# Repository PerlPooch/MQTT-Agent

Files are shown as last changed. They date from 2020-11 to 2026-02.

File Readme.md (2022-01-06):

# Spencer MQTT Agent

## MQTT Topic

	spencer/<ID>/<device>
		<ID> := unique MAC address of device
		<device> := temperature|status|relay
		
## Payload (JSON object):

	{
		"command": "fetch"|"set-rate"|"set"
		"rate": int: seconds between updates
		"device-num": int: 0-based index of device 
		"state": "on"|"off"|"pulse"
	}

	command == "fetch"
		Causes agent to publish information for <device>

	command == "set-rate"
		Sets update rate for <device> to rate in rate. <device> can be temperature or status

	command == "set"
		Sets <device> at index device-num to state. <device> can be relay. <state> can be on, off, or pulse.
		
## Examples:

	spencer/FC:F5:C4:AB:56:24/temperature {"command":"set-rate", "rate":"120"}
		Set the update rate for temperature reports to be 120 seconds

	spencer/FC:F5:C4:AB:56:24/status {"command":"set-rate", "rate":"300"}
		Set the update rate for status reports to be 300 seconds

	spencer/FC:F5:C4:AB:56:24/relay {"command":"set", "device-num":"1", "state":"on"}
		Turn on relay 0

	spencer/FC:F5:C4:AB:56:24/relay {"command":"set", "device-num":"1", "state":"off"}
		Turn off relay 1

	spencer/FC:F5:C4:AB:56:24/relay {"command":"set", "device-num":"0", "state":"pulse"}
		Pulse relay 0

	spencer/FC:F5:C4:AB:56:24/temperature {"command":"fetch"}
		Request publish of temperature

	spencer/FC:F5:C4:AB:56:24/status {"command":"fetch"}
		Request publish of input status

	spencer/FC:F5:C4:AB:56:24/relay {"command":"fetch"}
		Request publish of relay status

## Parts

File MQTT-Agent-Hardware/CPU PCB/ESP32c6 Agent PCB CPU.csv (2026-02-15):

Id | Designator | Footprint | Quantity | Designation | Supplier and ref
1 | J1 | Connector SIP-14-Soldertail-R | 1 | Screw_Terminal_01x14
2 | R2,R1,R3,R4 | R_1206_3216Metric_Pad1.30x1.75mm_HandSolder | 4 | 10K
3 | SW1,SW2,SW3 | SW_PUSH_6mm_H4.3mm | 3 | SW_Push
4 | U2 | DFPlayer | 1 | DFPlayer_Module
5 | C3,C4 | C_1206_3216Metric_Pad1.33x1.80mm_HandSolder | 2 | X7R 100nF 25V
6 | C1,C2 | C_0805_2012Metric_Pad1.18x1.45mm_HandSolder | 2 | X7R 1.0uF 25V
7 | U5 | XIAO-ESP32C6-DIP | 1 | XIAO-ESP32-C6
8 | R12 | R_1206_3216Metric_Pad1.30x1.75mm_HandSolder | 1 | 4.7K
9 | U1 | SSD1306-128x32 | 1 | ~
10 | J2 | Molex_KK-254_AE-6410-02A_1x02_P2.54mm_Vertical | 1 | Power
11 | R5 | R_1206_3216Metric_Pad1.30x1.75mm_HandSolder | 1 | 1K
12 | U6 | SSOP-14_5.3x6.2mm_P0.65mm | 1 | 74AHCT125

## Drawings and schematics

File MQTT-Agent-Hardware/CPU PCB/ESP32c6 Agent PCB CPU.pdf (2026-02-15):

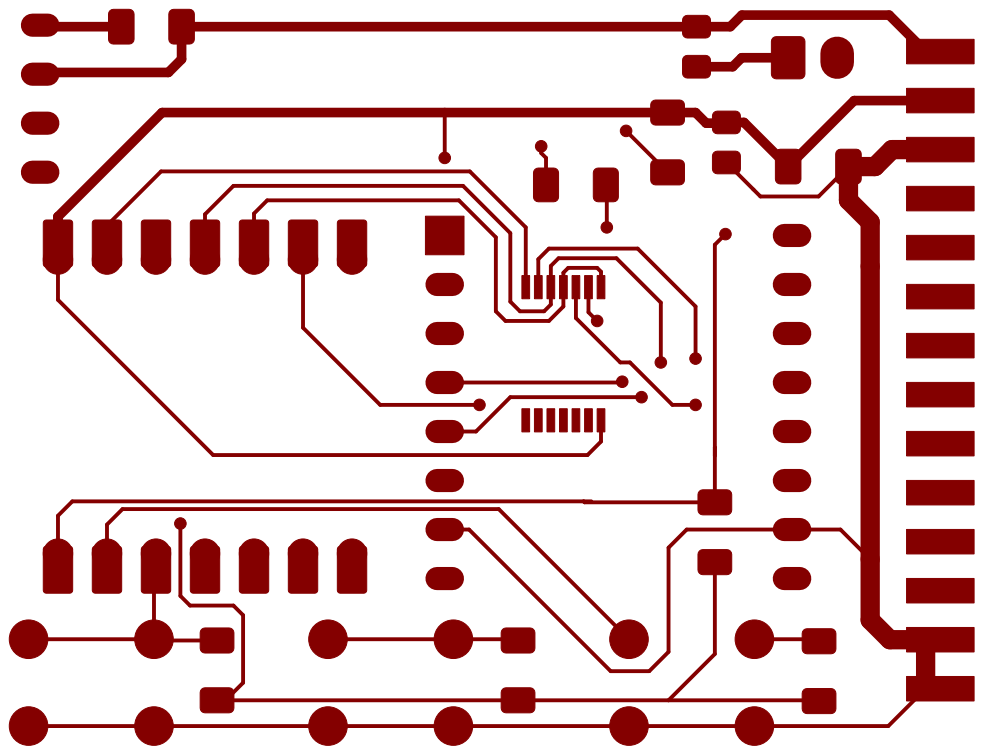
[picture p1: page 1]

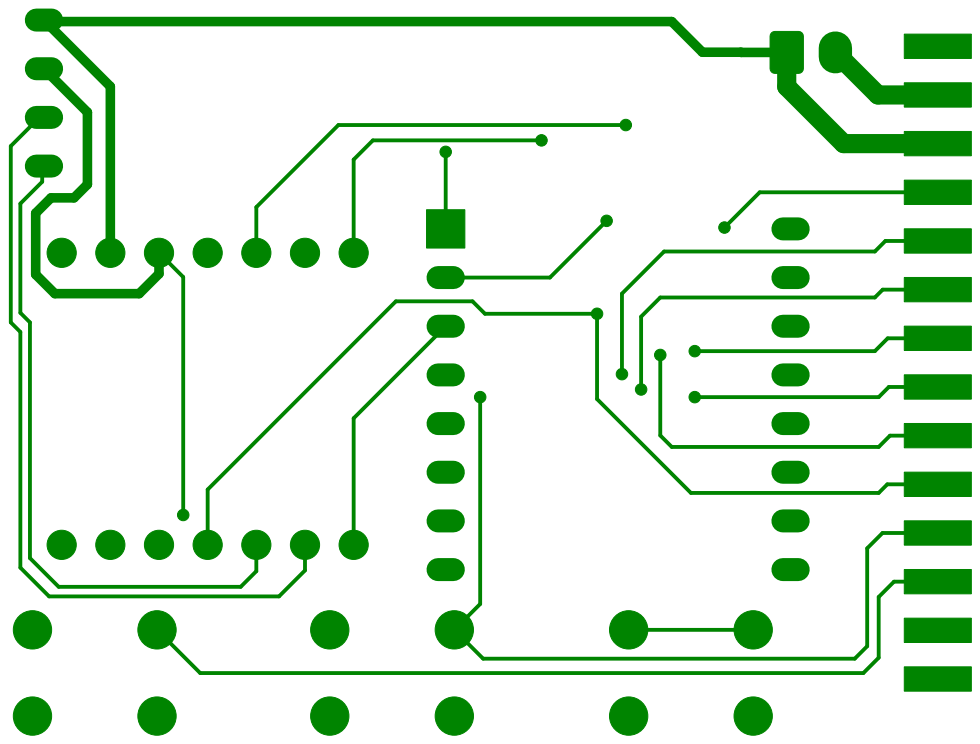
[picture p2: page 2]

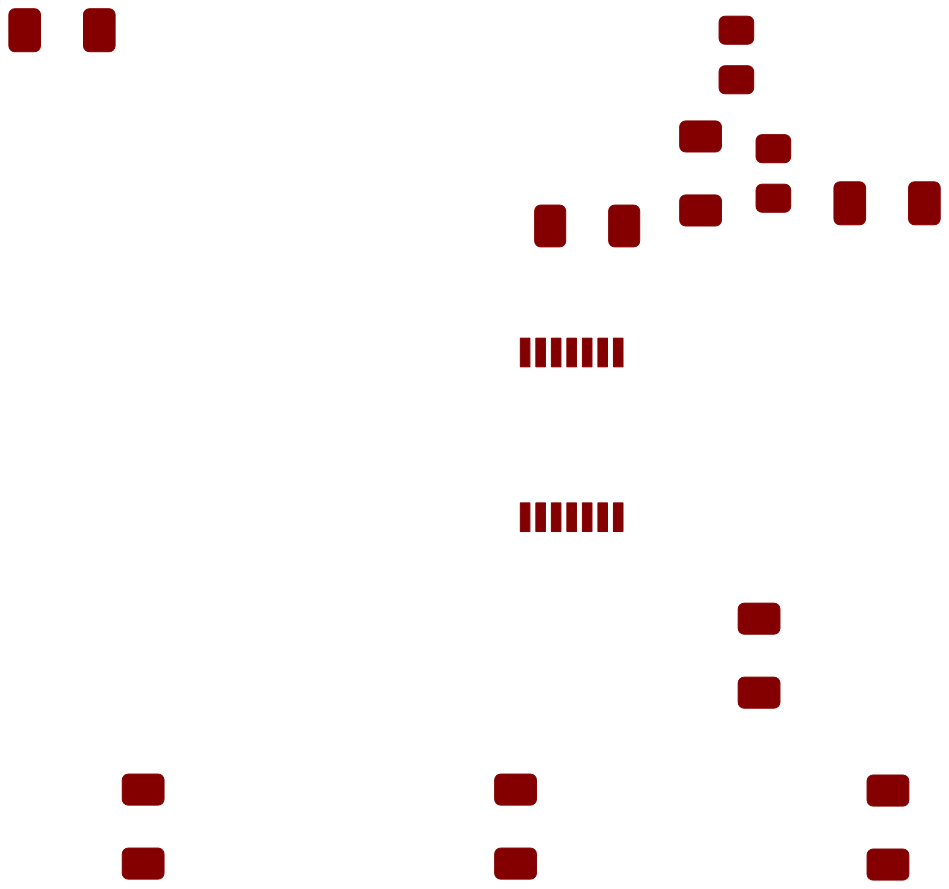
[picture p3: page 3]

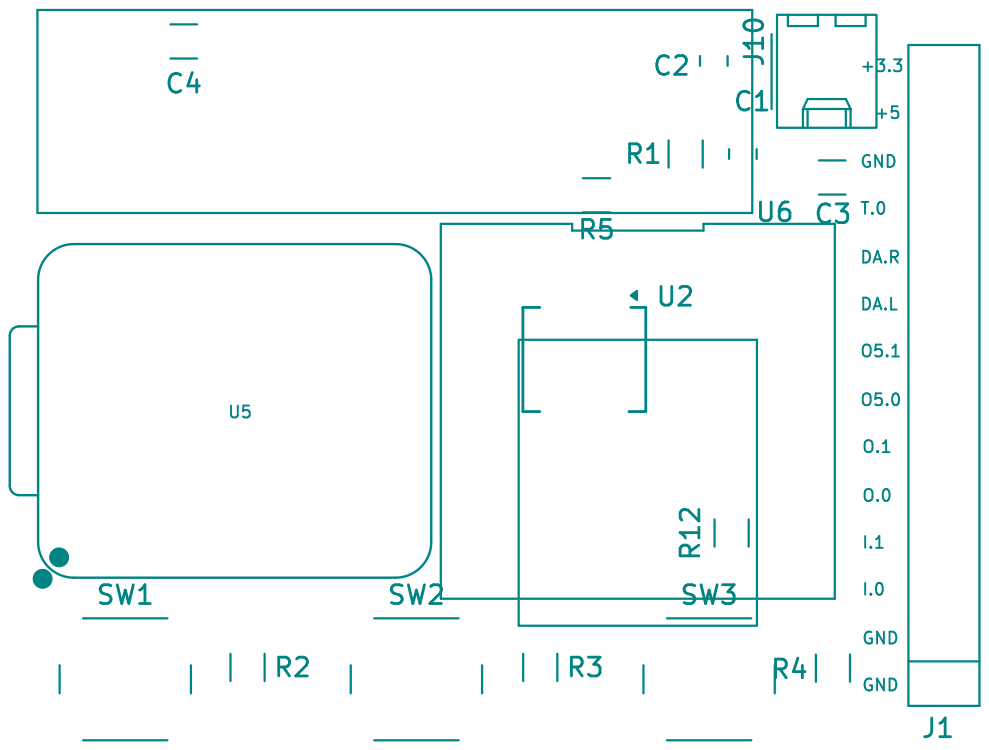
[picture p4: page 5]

+3.3 GND O5.0 DA.R GND O5.1 +5 DA.L T.0

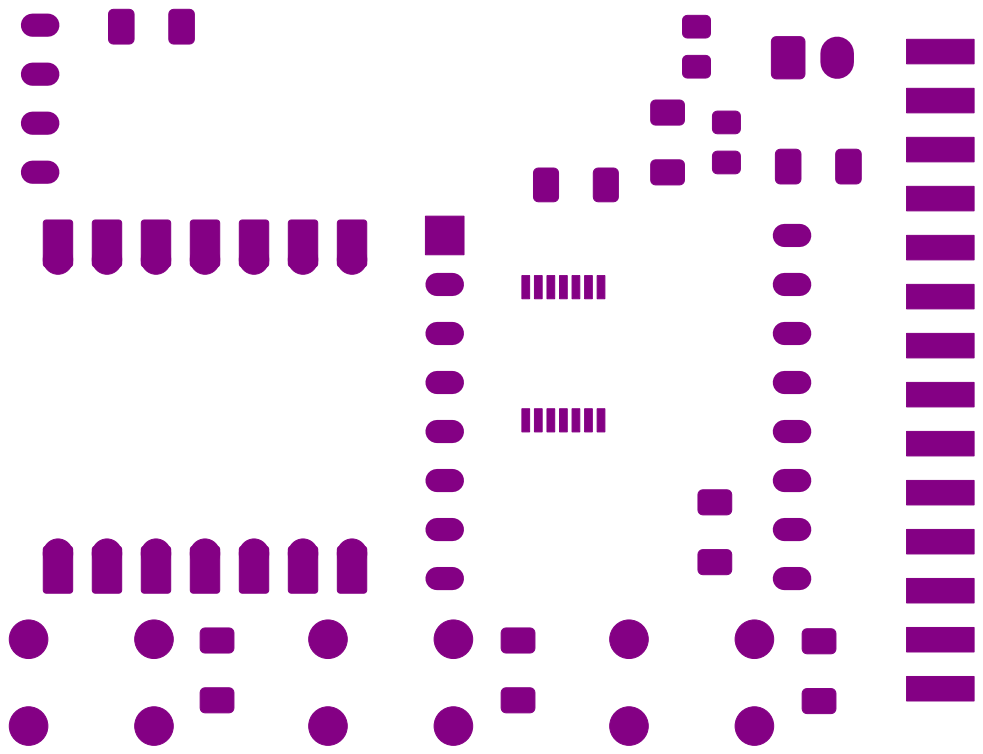
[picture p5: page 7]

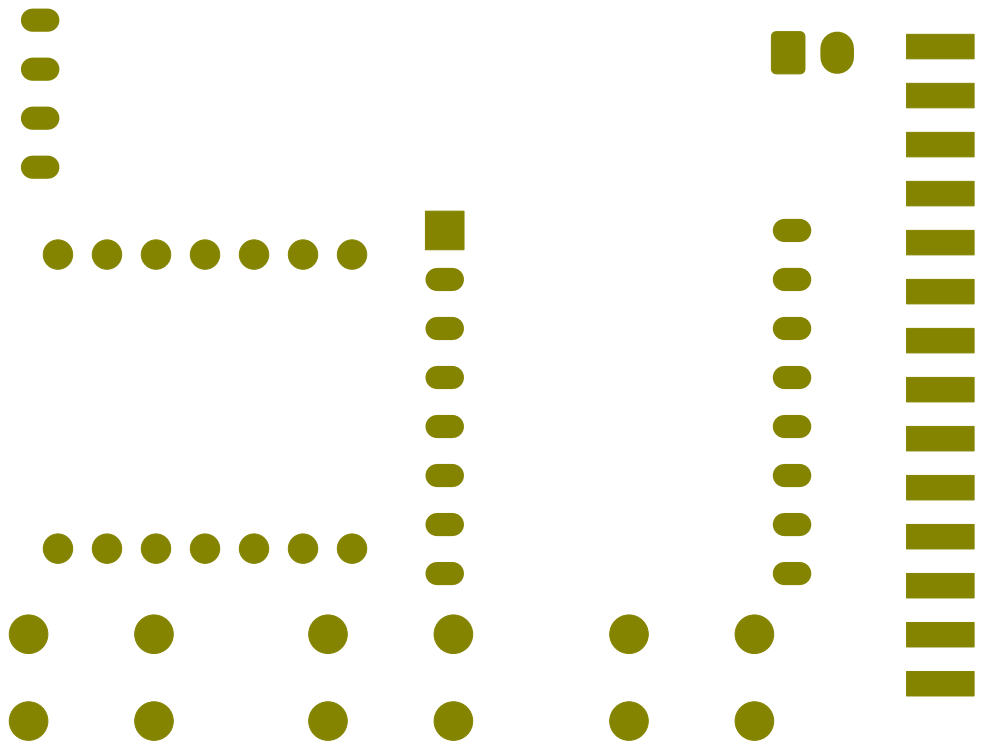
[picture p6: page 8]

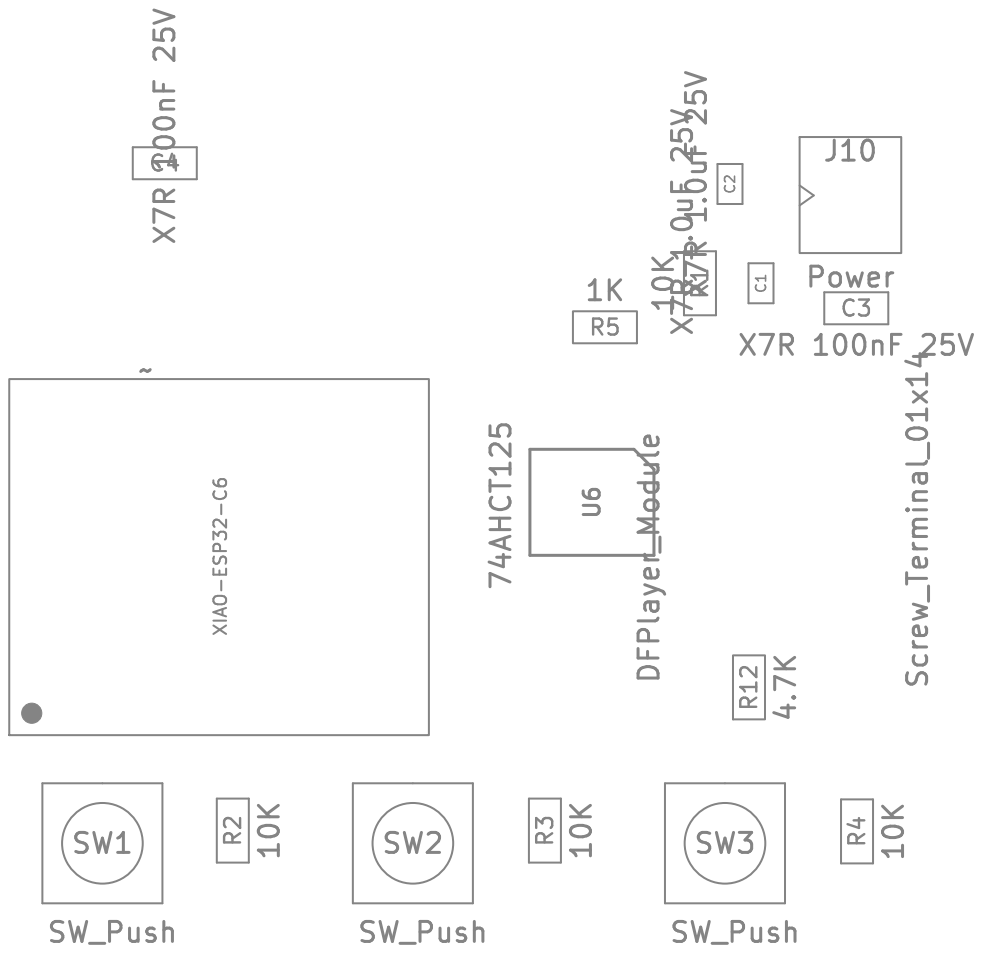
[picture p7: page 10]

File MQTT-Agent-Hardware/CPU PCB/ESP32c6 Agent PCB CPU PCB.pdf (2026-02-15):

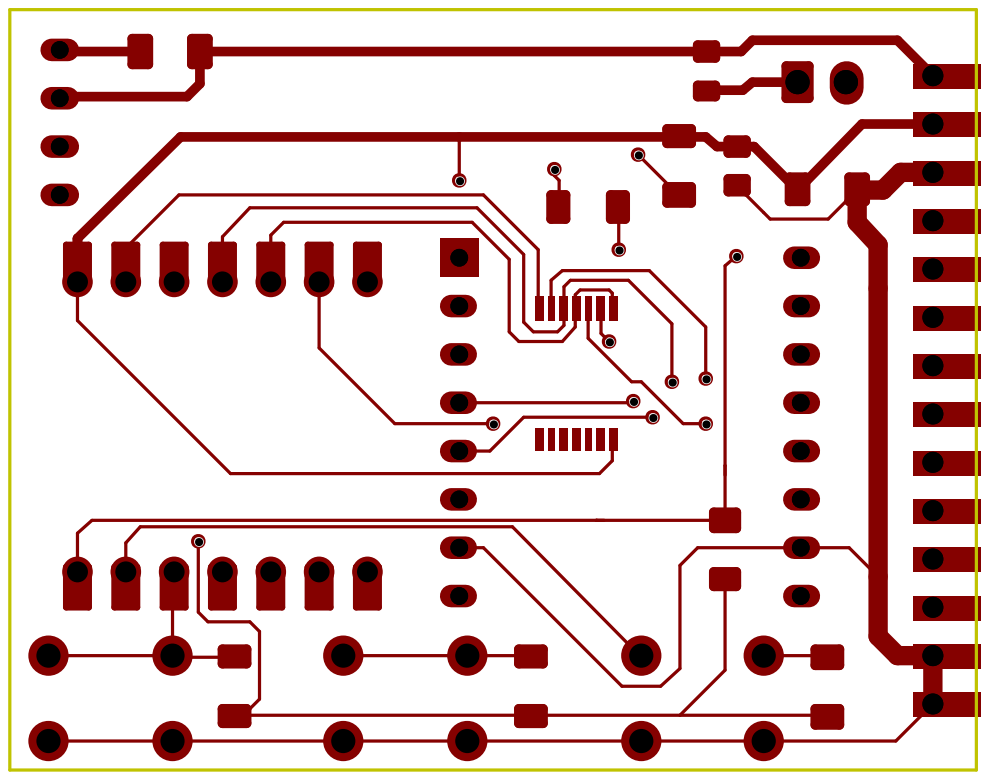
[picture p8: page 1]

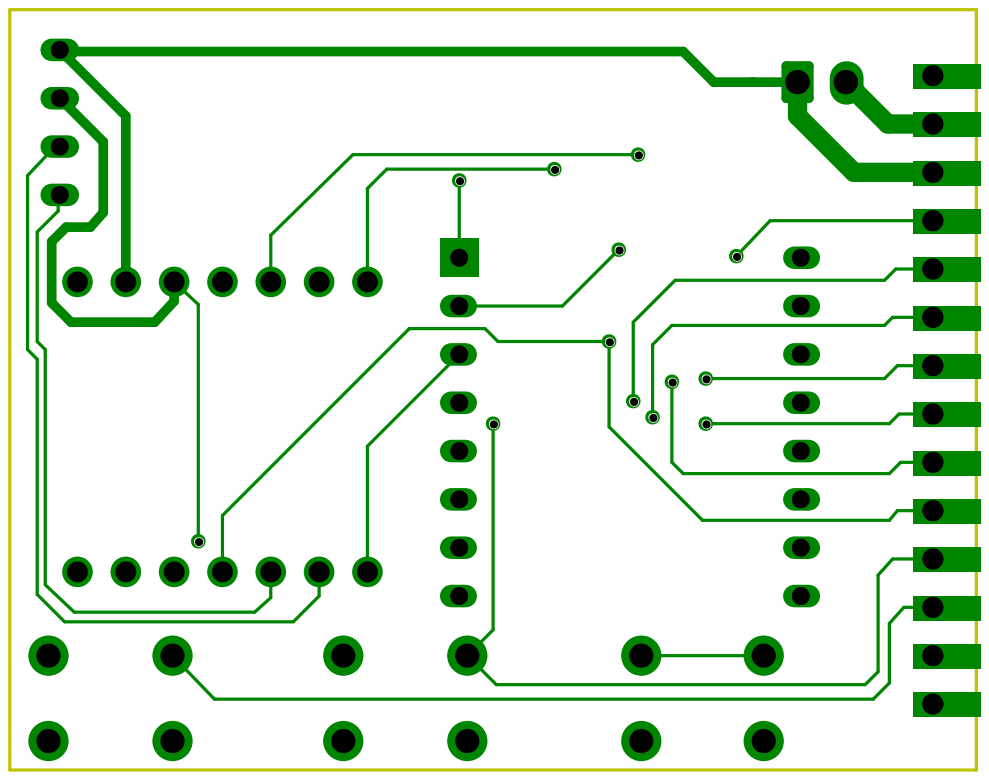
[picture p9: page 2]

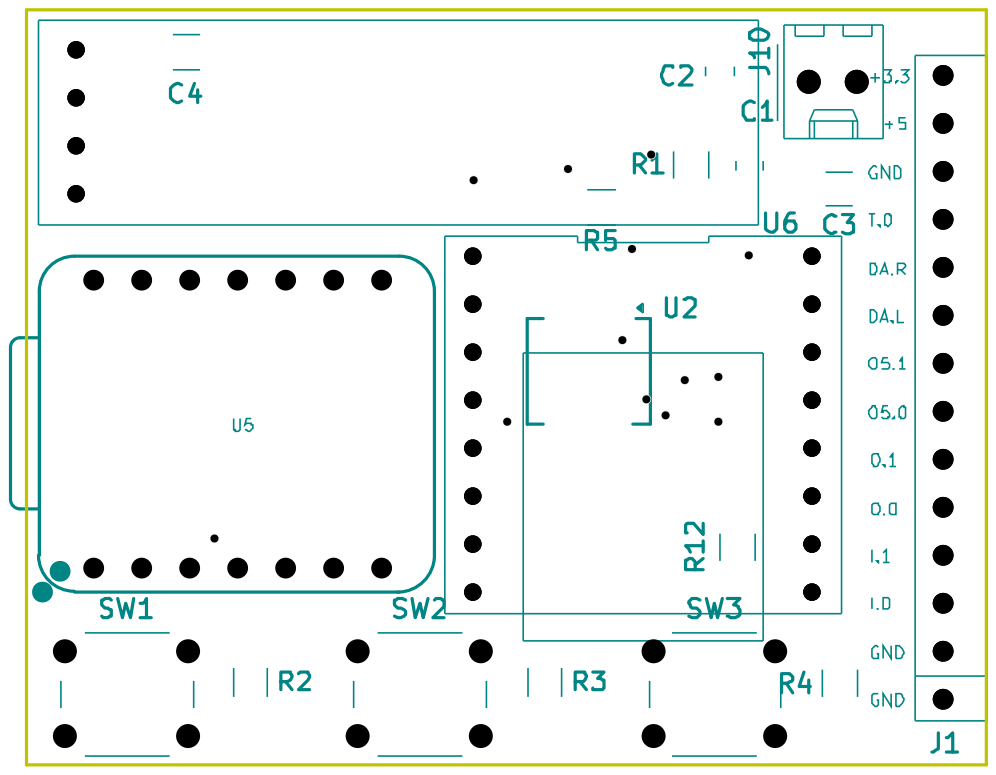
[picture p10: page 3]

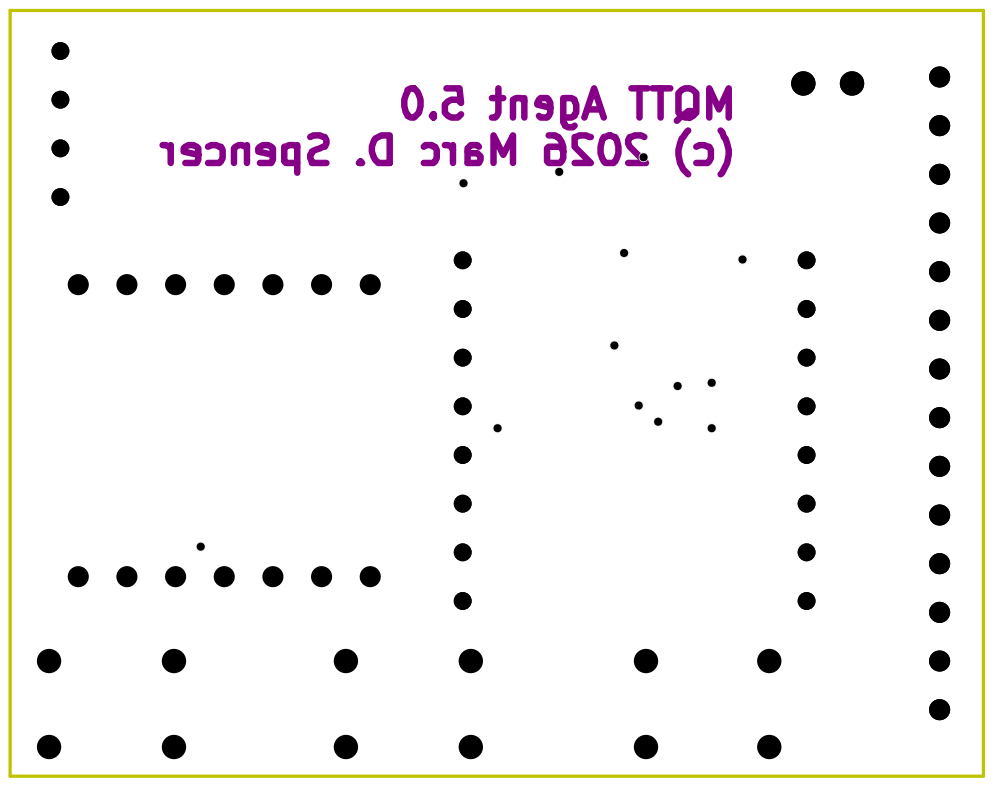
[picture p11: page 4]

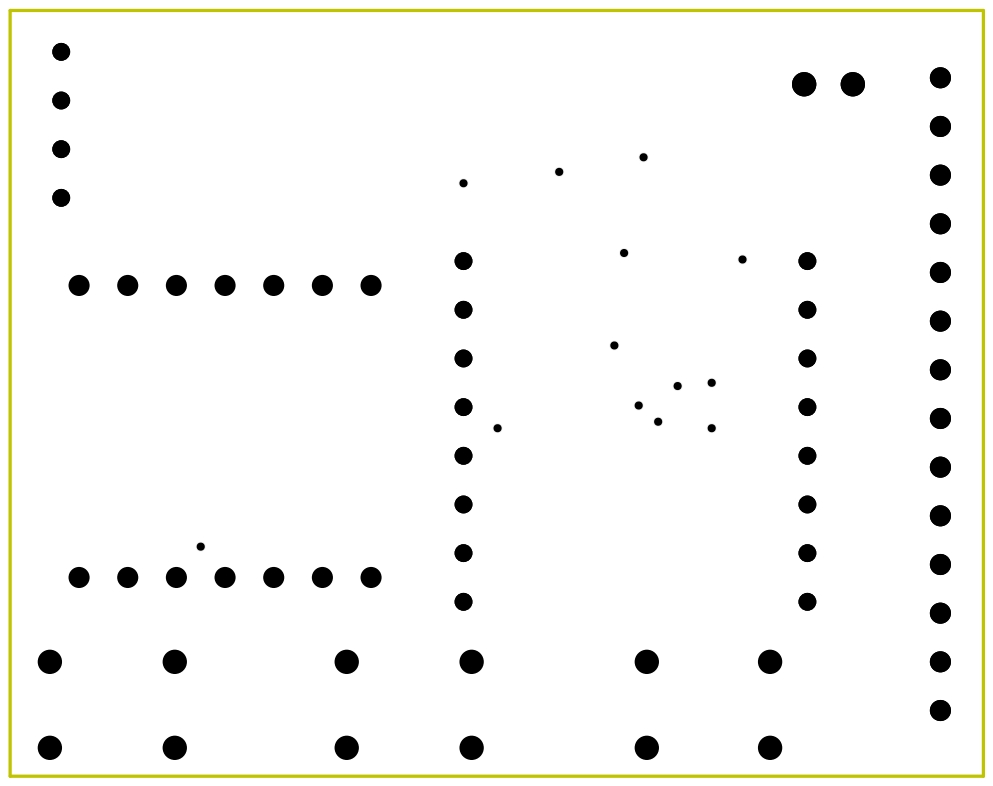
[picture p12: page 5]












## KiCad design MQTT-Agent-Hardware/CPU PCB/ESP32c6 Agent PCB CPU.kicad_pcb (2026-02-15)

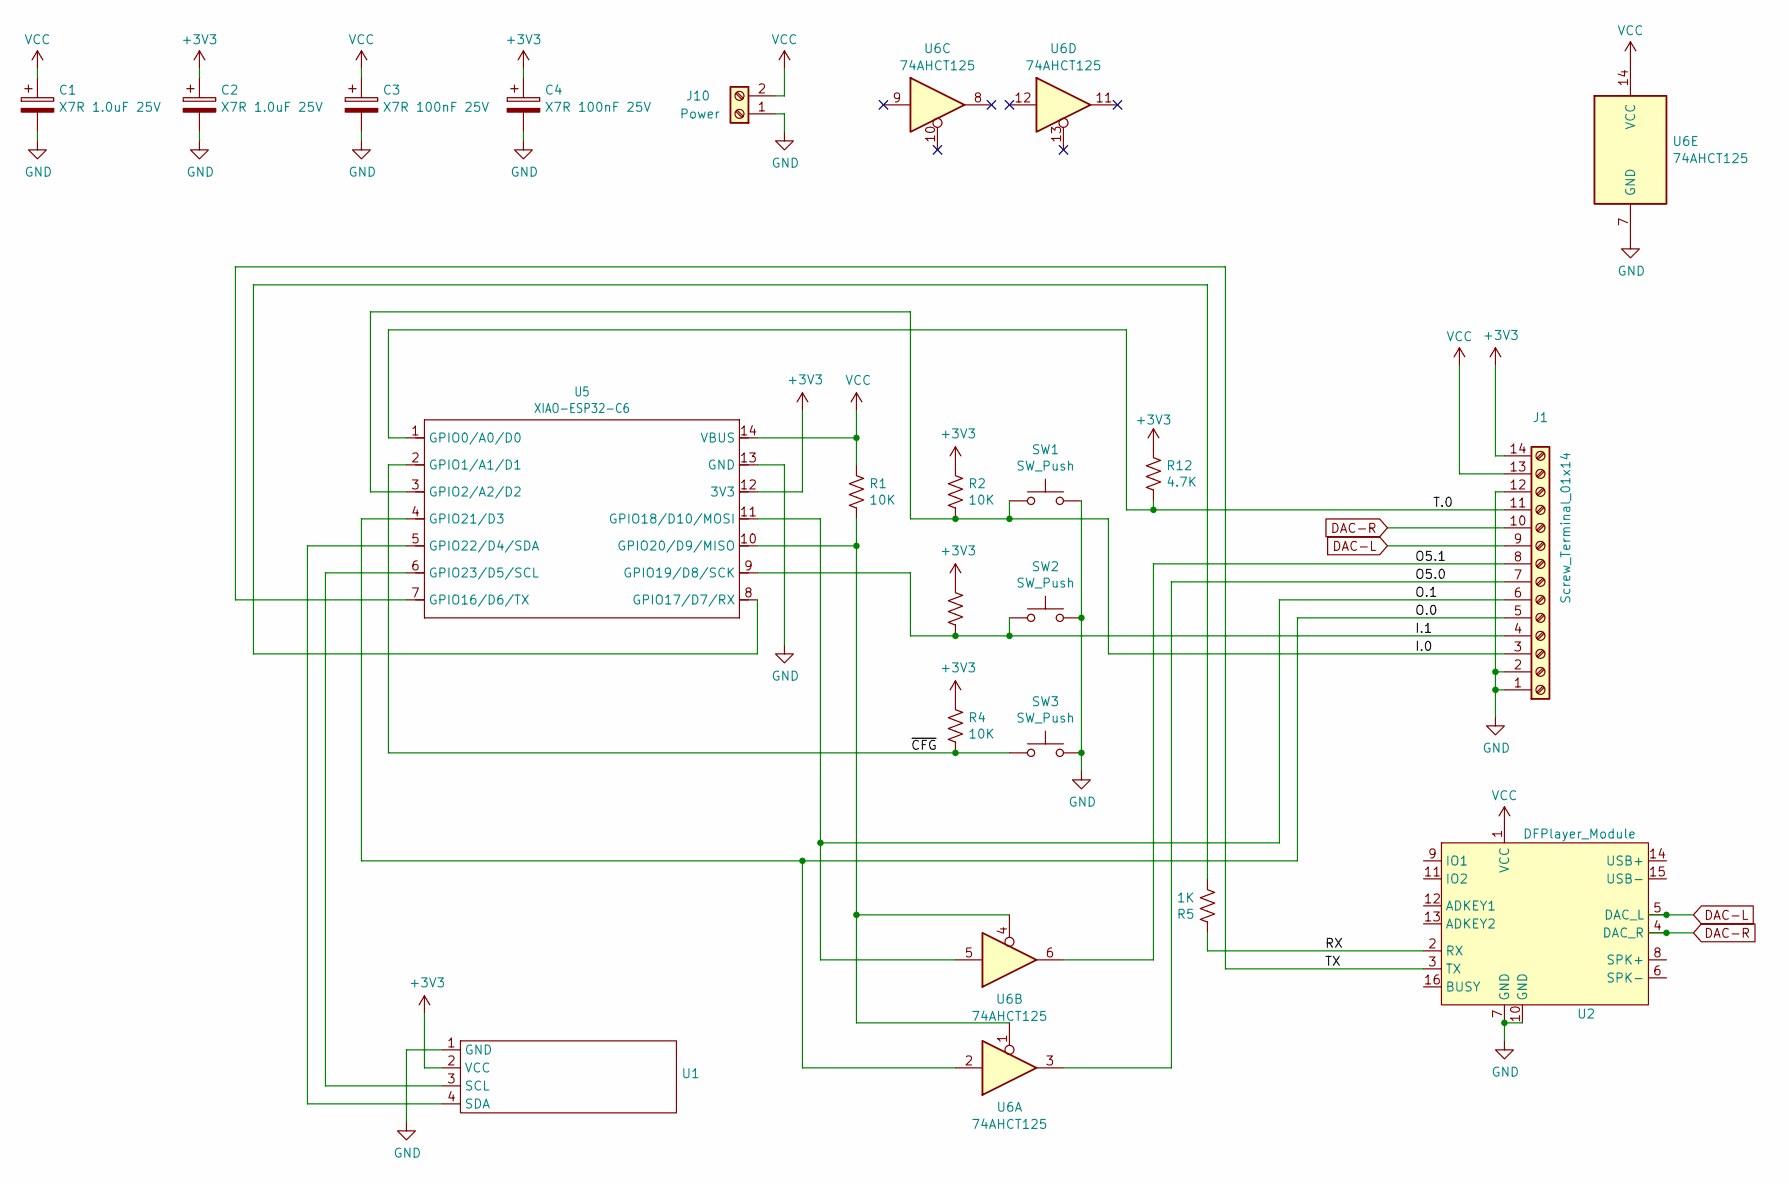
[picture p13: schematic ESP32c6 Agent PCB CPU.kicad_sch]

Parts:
C1, C2: X7R 1.0uF 25V; C_0805_2012Metric_Pad1.18x1.45mm_HandSolder
C3, C4: X7R 100nF 25V; C_1206_3216Metric_Pad1.33x1.80mm_HandSolder
J1: Screw_Terminal_01x14; Connector SIP-14-Soldertail-R
J10: Power; Molex_KK-254_AE-6410-02A_1x02_P2.54mm_Vertical
R1, R2, R3, R4: 10K; R_1206_3216Metric_Pad1.30x1.75mm_HandSolder
R5: 1K; R_1206_3216Metric_Pad1.30x1.75mm_HandSolder
R12: 4.7K; R_1206_3216Metric_Pad1.30x1.75mm_HandSolder
SW1, SW2, SW3: SW_Push; SW_PUSH_6mm_H4.3mm
U1: SSD1306-128x32
U2: DFPlayer_Module; DFPlayer
U5: XIAO-ESP32-C6; XIAO-ESP32C6-DIP
U6: 74AHCT125; SSOP-14_5.3x6.2mm_P0.65mm

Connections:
+3V3: C2.1, C4.1, J1.14, R2.1, R3.1, R4.1, R12.1, U1.2 (VCC), U5.12 (3V3)
/I.0: J1.3, R2.2, SW1.1, U5.3 (GPIO2/A2/D2)
/I.1: J1.4, R3.2, SW2.1, U5.9 (GPIO19/D8/SCK)
/O5.0: J1.7, U6.3
/O5.1: J1.8, U6.6
/O.0: J1.5, U5.4 (GPIO21/D3), U6.2
/O.1: J1.6, U5.11 (GPIO18/D10/MOSI), U6.5
/RX: R5.1, U2.2 (RX)
/T.0: J1.11, R12.2, U5.1 (GPIO0/A0/D0)
/TX: U2.3 (TX), U5.7 (GPIO16/D6/TX)
/~CFG: R4.2, SW3.1, U5.2 (GPIO1/A1/D1)
DAC-L: J1.9, U2.5 (DAC_L)
DAC-R: J1.10, U2.4 (DAC_R)
GND: C1.2, C2.2, C3.2, C4.2, J1.1, J1.2, J1.12, J10.1, SW1.2, SW2.2, SW3.2, U1.1 (GND), U2.7 (GND), U2.10 (GND), U5.13 (GND), U6.7 (GND); also elsewhere on the board
unnamed: U1.3 (SCL), U5.6 (GPIO23/D5/SCL)
unnamed: U1.4 (SDA), U5.5 (GPIO22/D4/SDA)
unnamed: R5.2, U5.8 (GPIO17/D7/RX)
unnamed: R1.2, U5.10 (GPIO20/D9/MISO), U6.1, U6.4
VCC: C1.1, C3.1, J1.13, J10.2, R1.1, U2.1 (VCC), U5.14 (VBUS), U6.14 (VCC); also elsewhere on the board

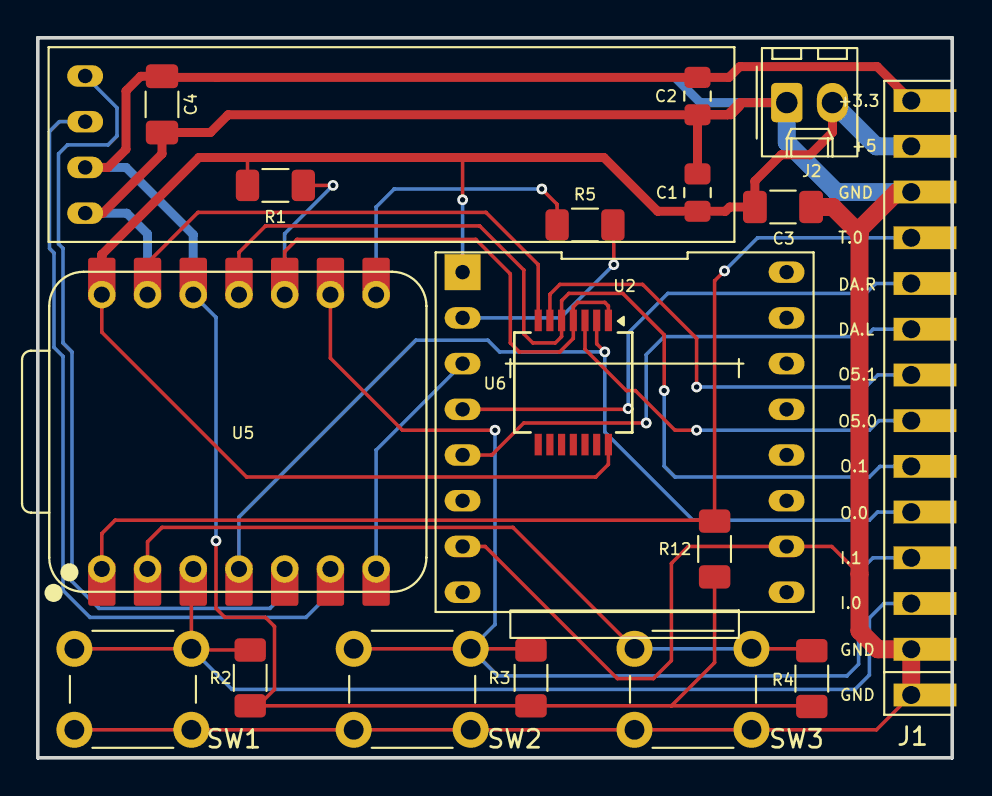
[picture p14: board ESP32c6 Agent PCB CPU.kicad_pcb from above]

Board: 2 copper layers, 50.8 x 40.0 mm, 19 parts (0 on the bottom side), 19 nets.

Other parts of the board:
J2: Power; Molex_KK-254_AE-6410-02A_1x02_P2.54mm_Vertical

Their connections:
GND: J2.1; also elsewhere on the board
VCC: J2.2; also elsewhere on the board

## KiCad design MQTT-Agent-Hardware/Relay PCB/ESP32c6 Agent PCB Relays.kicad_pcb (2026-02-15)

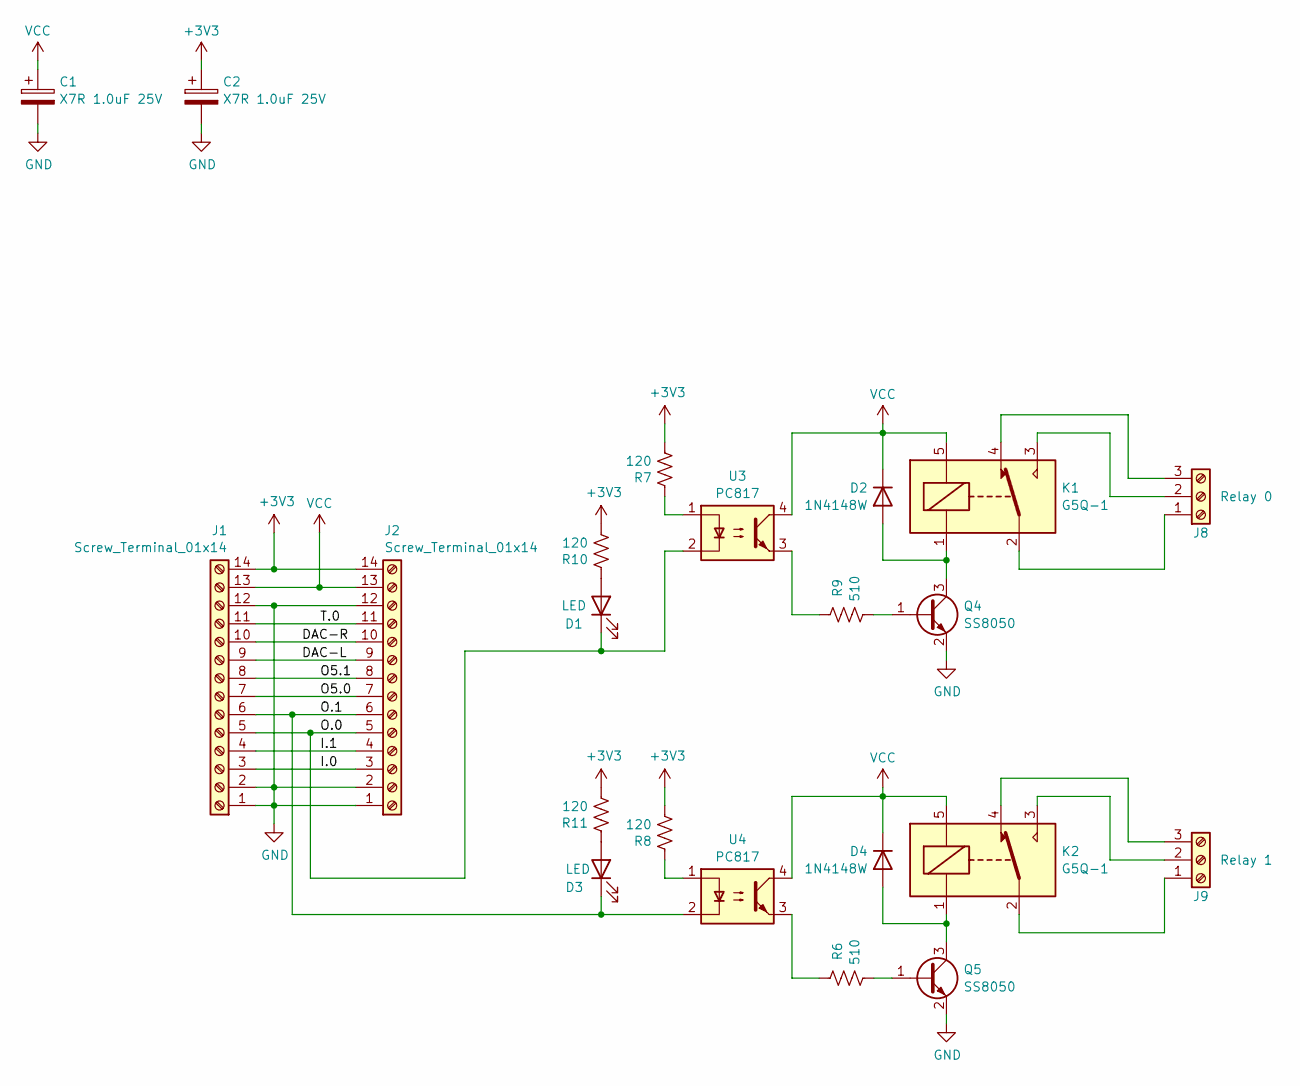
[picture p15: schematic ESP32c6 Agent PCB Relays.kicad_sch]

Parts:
C1, C2: X7R 1.0uF 25V; C_0805_2012Metric_Pad1.18x1.45mm_HandSolder
D1, D3: LED; LED_1206_3216Metric_Pad1.42x1.75mm_HandSolder
D2, D4: 1N4148W; D_SOD-123
J1: Screw_Terminal_01x14; Connector SIP-14-Soldertail-L
J2: Screw_Terminal_01x14; Connector SIP-14-Soldertail-R
J8: Relay 0; Molex_KK-254_AE-6410-03A_1x03_P2.54mm_Vertical
J9: Relay 1; Molex_KK-254_AE-6410-03A_1x03_P2.54mm_Vertical
K1, K2: G5Q-1; Relay_SPDT_Omron-G5Q-1
Q4, Q5: SS8050; SOT-23
R6, R9: 510; R_1206_3216Metric_Pad1.30x1.75mm_HandSolder
R7, R8, R10, R11: 120; R_1206_3216Metric_Pad1.30x1.75mm_HandSolder
U3, U4: PC817; DIP-4_W7.62mm

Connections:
+3V3: C2.1, J1.14, J2.14, R7.2, R8.2, R10.2, R11.2
/DAC-L: J1.9, J2.9
/DAC-R: J1.10, J2.10
/I.0: J1.3, J2.3
/I.1: J1.4, J2.4
/O5.0: J1.7, J2.7
/O5.1: J1.8, J2.8
/O.0: D1.1 (K), J1.5, J2.5, U3.2
/O.1: D3.1 (K), J1.6, J2.6, U4.2
/T.0: J1.11, J2.11
GND: C1.2, C2.2, J1.1, J1.2, J1.12, J2.1, J2.2, J2.12, Q4.2 (E), Q5.2 (E)
unnamed: D1.2 (A), R10.1
unnamed: D2.2 (A), K1.1, Q4.3 (C)
unnamed: D3.2 (A), R11.1
unnamed: D4.2 (A), K2.1, Q5.3 (C)
unnamed: J8.1, K1.2
unnamed: J8.2, K1.3
unnamed: J8.3, K1.4
unnamed: J9.1, K2.2
unnamed: J9.2, K2.3
unnamed: J9.3, K2.4
unnamed: Q4.1 (B), R9.2
unnamed: Q5.1 (B), R6.2
unnamed: R6.1, U4.3
unnamed: R7.1, U3.1
unnamed: R8.1, U4.1
unnamed: R9.1, U3.3
VCC: C1.1, D2.1 (K), D4.1 (K), J1.13, J2.13, K1.5, K2.5, U3.4, U4.4

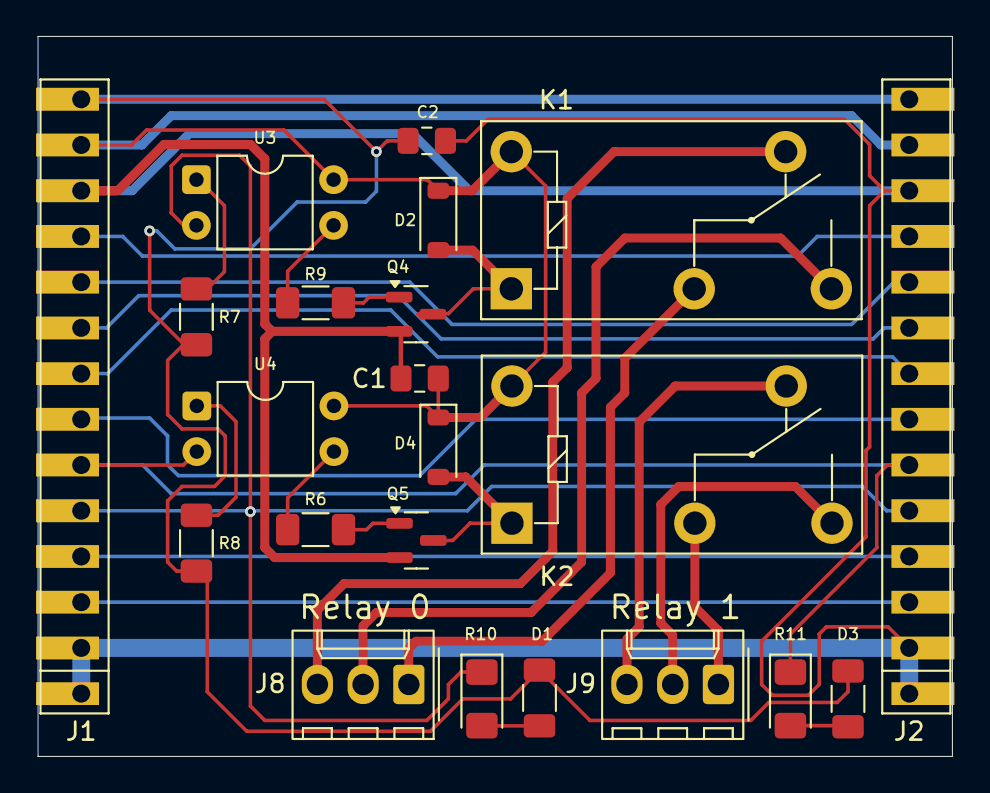
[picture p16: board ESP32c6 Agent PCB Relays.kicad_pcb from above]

Board: 2 copper layers, 50.8 x 40.0 mm, 22 parts (0 on the bottom side), 28 nets.

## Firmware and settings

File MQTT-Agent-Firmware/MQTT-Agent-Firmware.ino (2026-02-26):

#include "MDS_Platform.h"

// ---- Configuration -------------------------------------------------------------------
//
#define USE_STATUS_0
// STATUS_1 and DFPlayer are mutually exclusive
#define USE_STATUS_1
#define INVERT_STATUS
// #define USE_RELAY_0
// RELAY_1 and DFPlayer are mutually exclusive
// #define USE_RELAY_1
// #define USE_DFPLAYER
// #define PLAY_TRIGGER_RELAY_0
// #define USE_MIDI
#define RELAY_POSITIVE_LOGIC
// #define RELAY_NEGATIVE_LOGIC
#define USE_1WIRE_TEMPERATURE
// #define USE_DHT11_TEMPERATURE
// #define ROTATE_DISPLAY
//
// --------------------------------------------------------------------------------------

#if IS_ESP8266
	#include <ESP8266WiFi.h>
	#include <ESP8266WebServer.h>
#elif IS_ESP32
	#include <WiFi.h>
	#include <WebServer.h>
	#include <esp_mac.h>
#endif
#include <WiFiManager.h>
#include <Update.h>
#include <ArduinoJson.h>
#include <PubSubClient.h>
#ifdef USE_1WIRE_TEMPERATURE
#include <OneWire.h>
#include <DallasTemperature.h>
#endif
#include <arduino-timer.h>
#include <FS.h>
#include <LittleFS.h>
#include <SPI.h>
#include <Wire.h>
#include <Adafruit_GFX.h>
#include <Adafruit_SSD1306.h>
#ifdef USE_DHT11_TEMPERATURE
#include "DHT.h"
#endif
#ifdef USE_DFPLAYER
	#if IS_ESP8266
		#include <SoftwareSerial.h>
	#endif
#include <DFRobotDFPlayerMini.h>
#endif
#ifdef USE_MIDI
	#include <MIDI.h>
	#if IS_ESP8266
		#include <SoftwareSerial.h>
	#endif
#endif


#define VERSION				"2.2"
#define ACCESSPOINT_NAME	"MQA"

#define SCREEN_WIDTH		128		// OLED display width, in pixels
#define SCREEN_HEIGHT		32		// OLED display height, in pixels
#define OLED_RESET    		-1		// Reset pin # (or -1 if sharing Arduino reset pin)
// #define DEBUG_D						// Mirror screen to serial

#if IS_ESP8266
	// LED
	#define PIN_LED 			16
	#define PIN_LED_1			2
	// I2C OLED
	#define PIN_I2C_SDA			4
	#define PIN_I2C_SCL			5
	// DFPlayer
	#define PIN_DFP_RX			13
	#define PIN_DFP_TX			2
	// Inputs
	#define PIN_RESET_WIFI 		12
	#ifdef USE_STATUS_0
		#define PIN_STATUS_0 	10
	#endif
	#ifdef USE_STATUS_1
		#define PIN_STATUS_1 	13
	#endif
	// 1-wire temp
	#define PIN_TEMP_0		 	14
	// Relay
	#if defined (USE_RELAY_0) || defined (PLAY_TRIGGER_RELAY_0)
		#define PIN_RELAY_0 	0
	#endif
	#ifdef USE_RELAY_1
		#define PIN_RELAY_1 	2
	#endif
#elif IS_ESP32 && IS_ESP32C6
	// LED
	#ifndef LED_BUILTIN
		#define LED_BUILTIN		15
	#endif
	#define PIN_LED				LED_BUILTIN
	// I2C OLED
	#define PIN_I2C_SDA			SDA    // D4 / GPIO22
	#define PIN_I2C_SCL			SCL    // D5 / GPIO23
	// DFPlayer
	#define DFP_UART_NUM		1
	#define PIN_DFP_TX			D6    // GPIO16
	#define PIN_DFP_RX			D7    // GPIO17
	// Inputs
	#define PIN_RESET_WIFI		D1  // GPIO1  (button to GND, INPUT_PULLUP)
	#ifdef USE_STATUS_0
		#define PIN_STATUS_0	D2  // GPIO2  (INPUT_PULLUP)
	#endif
	#ifdef USE_STATUS_1
		#define PIN_STATUS_1 	D8	// GPIO19
	#endif
	// 1-wire temp
	#define PIN_TEMP_0			D0   // GPIO0  (1-wire)
	// Relay
	#if defined(USE_RELAY_0) || defined(PLAY_TRIGGER_RELAY_0)
		#define PIN_RELAY_0		D3   // GPIO21
	#endif
	#ifdef USE_RELAY_1
		#define PIN_RELAY_1 	D10
	#endif
#else
#endif

// if relay is disabled, don't allow play-trigger
#if !defined(USE_RELAY_0)
  #undef PLAY_TRIGGER_RELAY_0
#endif

#define DHT_TYPE				DHT11

#define CONFIG_FILE				"/config.json"


#define	DEFAULT_MQTT_PORT		1883
#define	DEFAULT_TEMP_RATE		10
#define	DEFAULT_STATUS_RATE		60

#define	DISPLAY_TIMEOUT			5000	// Time(ms) between each display scroll
#define	DISPLAY_LINES			4		// Number of text lines that fit on the display
#define	RELAY_TIMEOUT			500 	// Time(ms) for relay pulses
#define	HAPPY_PERIOD			5000	// Time(ms) for happy LED blinks
#define	HAPPY_NOMQTT_PERIOD		10000	// Time(ms) for happy LED blinks
#define	DFPLAYER_RESET			3600	// Time(s) between resetting DFPlayer
#define ONLINE_CHECK_PERIOD 	10000	// Time(ms) between checks to see if we're still online
#define REBOOT_DAYS				7		// Reboot every N days
#define WIFI_RETRY_PERIOD		10000UL	// Time(ms) between WiFi connection retries
#define REBOOT_BUTTON_TIME		10000	// Time(ms) WiFi button down to cause Reboot

#ifdef RELAY_POSITIVE_LOGIC
	#define LOGIC_HIGH 1
	#define LOGIC_LOW 0
#else
	#define LOGIC_HIGH 0
	#define LOGIC_LOW 1
#endif

#define MS_PER_DAY				(24UL * 60UL * 60UL * 1000UL)

char				systemID[32];		// System ID. Based on the WiFi MAC

#if IS_ESP8266
ESP8266WebServer 	Server;
#elif IS_ESP32
WebServer 			Server;
#endif

#ifdef USE_1WIRE_TEMPERATURE
OneWire 			oneWire(PIN_TEMP_0);
DallasTemperature 	sensors(&oneWire);
#endif

#ifdef USE_DHT11_TEMPERATURE
DHT					dht(PIN_TEMP_0, DHT_TYPE);
#endif

#ifdef USE_DFPLAYER
	#if IS_ESP8266
		SoftwareSerial mySoftwareSerial(PIN_DFP_RX, PIN_DFP_TX); // RX, TX
	#elif IS_ESP32
		HardwareSerial mySoftwareSerial(DFP_UART_NUM);
	#endif
DFRobotDFPlayerMini dfp;
#endif

#ifdef USE_MIDI
SoftwareSerial mySerial(16, 0); // RX, TX  D0, D3
// MIDI_NAMESPACE::SerialMIDI<SoftwareSerial> serialMIDI(mySerial);
// MIDI_NAMESPACE::MidiInterface<MIDI_NAMESPACE::SerialMIDI<SoftwareSerial>> MIDI((MIDI_NAMESPACE::SerialMIDI<SoftwareSerial>&)serialMIDI);
MIDI_CREATE_INSTANCE(SoftwareSerial, mySerial, midiA);
#endif

WiFiClient 			wifiClient;
PubSubClient 		client(wifiClient);

Adafruit_SSD1306	display(SCREEN_WIDTH, SCREEN_HEIGHT, &Wire, OLED_RESET);

Timer<>::Task		happyBlinkTimer;
Timer<>::Task		scrollTimer;
Timer<>::Task		temperatureTimer;
Timer<>::Task		statusTimer;
#ifdef USE_DFPLAYER
Timer<>::Task		dfplayerTimer;
#endif

auto					timer = timer_create_default();
unsigned long			lastMQTTOnlineCheck;
static unsigned long	rebootPressedTime = 0;
static uint32_t			wifiIdleSince = 0;
static unsigned long	wifiNextRetry = 0;
static bool				wifiEverUp = false;
static bool				wifiProvisioning = false;

static uint32_t	rebootTime = (uint32_t)((uint32_t)REBOOT_DAYS * MS_PER_DAY);

struct AppConfig {
	char		MQTTBroker[64];
	uint16_t	MQTTPort;
	uint16_t	temperatureUpdateRate;
	uint16_t	statusUpdateRate;
};
AppConfig appConfig;

struct temperature_t {
	char	address[24];	// "XX:XX:XX:XX:XX:XX:XX:XX" + '\0'
	float	tempF;
	bool	valid;
} ;

// === Upload/Update
static volatile bool shouldReboot = false;

static void handleUploadPage();
static void handleUploadPost();
static void handleUploadStream();

// === WiFi Manager
static 					WiFiManager wm;
static bool 			wmShouldSave = false;
static bool				wmParamsAdded = false;

static void wmSaveCallback() {
	wmShouldSave = true;
}

static char wmMqttPort[6];     // "65535" + NUL
static char wmTempRate[6];
static char wmStatusRate[6];

static WiFiManagerParameter pMqttBroker(
	"mqttBroker",
	"MQTT Broker",
	appConfig.MQTTBroker,
	sizeof(appConfig.MQTTBroker)
);

static WiFiManagerParameter pMqttPort(
	"mqttPort",
	"MQTT Port",
	wmMqttPort,
	sizeof(wmMqttPort)
);

static WiFiManagerParameter pTempRate(
	"tempRate",
	"Temperature Update Rate (s)",
	wmTempRate,
	sizeof(wmTempRate)
);

static WiFiManagerParameter pStatusRate(
	"statusRate",
	"Status Update Rate (s)",
	wmStatusRate,
	sizeof(wmStatusRate)
);

static uint16_t parseU16(const char* s, uint16_t def) {
	if(!s || !*s) return def;

	char* end = nullptr;
	unsigned long v = strtoul(s, &end, 10);
	if(end == s) return def;
	if(v > 65535UL) return def;
	return (uint16_t)v;
}

static void normalizeAppConfigDefaults() {
	if(appConfig.MQTTPort == 0) appConfig.MQTTPort = DEFAULT_MQTT_PORT;
	if(appConfig.temperatureUpdateRate == 0) appConfig.temperatureUpdateRate = DEFAULT_TEMP_RATE;
	if(appConfig.statusUpdateRate == 0) appConfig.statusUpdateRate = DEFAULT_STATUS_RATE;
}

struct Screen {
	String		lines[DISPLAY_LINES];
};
Screen screen;

bool lastStatus0 = false, lastStatus1 = false;
bool reset_is_down = false;



#ifdef USE_DFPLAYER
void dfpPrintDetail(uint8_t type, int value) {
	switch (type) {
		case TimeOut:
			Serial.println(F("DFP: Timeout."));
			break;
		case WrongStack:
			Serial.println(F("DFP: Stack Wrong."));
			break;
		case DFPlayerCardInserted:
			Serial.println(F("DFP: Card Inserted."));
			D(F("Card Inserted."));
			break;
		case DFPlayerCardRemoved:
			Serial.println(F("DFP: Card Removed."));
			D(F("Card Removed."));
			break;
		case DFPlayerCardOnline:
			Serial.println(F("DFP: Card Online."));
			D(F("Card Online."));
			Serial.print(F("DFP: "));
			Serial.print(dfp.readFileCounts());
			Serial.println(F(" items on card."));
			D(dfp.readFileCounts() + " items.");
			break;
		case DFPlayerUSBInserted:
			Serial.println(F("DFP: USB Inserted."));
			break;
		case DFPlayerUSBRemoved:
			Serial.println(F("DFP: USB Removed."));
			break;
		case DFPlayerPlayFinished:
			Serial.print(F("DFP: item "));
			Serial.print(value);
			Serial.println(F(" Play finished."));
			D("Play " + String(value) + " finished.");
#ifdef PLAY_TRIGGER_RELAY_0
			delay(200);
			digitalWrite(PIN_RELAY_0, LOGIC_LOW);
#endif
#ifdef USE_MIDI
			midiA.sendNoteOff(61, 0, 1);     // Stop the note
#endif
			publishPlayStatus((void *)0, value, "complete");
		break;
		case DFPlayerError:
			Serial.print(F("DFP: Error, "));

			switch (value) {
				case Busy:
					Serial.println(F("Card not found"));
					break;
				case Sleeping:
					Serial.println(F("Sleeping"));
					break;
				case SerialWrongStack:
					Serial.println(F("Get Wrong Stack"));
					break;
				case CheckSumNotMatch:
					Serial.println(F("Check Sum Not Match"));
					break;
				case FileIndexOut:
					Serial.println(F("File Index Out of Bound"));
					break;
				case FileMismatch:
					Serial.println(F("Cannot Find File"));
					break;
				case Advertise:
					Serial.println(F("In Advertise"));
					break;
				default:
					break;
			}
			break;
		default:
			break;
	}  
}
#endif

void printFile(const char *filename) {
	File file = LittleFS.open(filename, "r");
	if (!file) {
		Serial.println(F("Unable to read file"));
		return;
	}

	while (file.available()) {
		Serial.print((char)file.read());
	}
	Serial.println();

	file.close();
}

void listDir(fs::FS &fs, const char *dirname){
	Serial.printf("  Directory %s:\n", dirname);

#if IS_ESP8266
	String str = "";
	Dir dir = fs.openDir(dirname);
	while (dir.next()) {
		str += F("    ");
		str += dir.fileName();
		str += F(" (");
		str += dir.fileSize();
		str += F("b)\n");
	}
	Serial.print(str);
#elif IS_ESP32
	File root = fs.open(dirname);
	if(!root || !root.isDirectory()) {
		Serial.println(F("    <not a directory>"));
		return;
	}

	for(File f = root.openNextFile(); f; f = root.openNextFile()) {
		Serial.print(F("    "));
		Serial.print(f.name());
		Serial.print(F(" ("));
		Serial.print((uint32_t)f.size());
		Serial.println(F("b)"));
	}
#endif
}

bool loadConfiguration(const char *filename, AppConfig &config) {
	File file = LittleFS.open(filename, "r");

	if (file) {
		StaticJsonDocument<512> doc;

		DeserializationError error = deserializeJson(doc, file);

		if (error) {
			Serial.println(F("Unable to read configuration"));
			file.close();
			return false;
		} else {
			strlcpy(config.MQTTBroker, doc["MQTTBroker"], sizeof(config.MQTTBroker));

			config.MQTTPort = doc["MQTTPort"];

			config.temperatureUpdateRate = doc["temperatureUpdateRate"];
//			if(config.temperatureUpdateRate == NULL) config.temperatureUpdateRate = 1;

			config.statusUpdateRate = doc["statusUpdateRate"];
//			if(config.statusUpdateRate == NULL) config.statusUpdateRate = 1;
		} 

		file.close();
		return true;
	} else {
		Serial.println(F("Unable to open configuration."));
		return false;
	}
}


void saveConfiguration(const char *filename, const AppConfig &config) {
	LittleFS.remove(filename);

	File file = LittleFS.open(filename, "w");
	if (!file) {
		Serial.println(F("Unable to create configuration file"));
		return;
	}

	StaticJsonDocument<512> doc;

	doc["MQTTBroker"] = config.MQTTBroker;
	doc["MQTTPort"] = config.MQTTPort;
	doc["temperatureUpdateRate"] = config.temperatureUpdateRate;
	doc["statusUpdateRate"] = config.statusUpdateRate;

	serializeJsonPretty(doc, Serial);

	if (serializeJson(doc, file) == 0) {
		Serial.println(F("Unable to write configuration file"));
	}

	file.close();
}

void configModeCallback(WiFiManager *myWM) {
  Serial.println("WiFi: Failed to Connect.");
  Serial.println("WiFi: Portal " + String(myWM->getConfigPortalSSID()));

  D("Failed to Connect.");
  D(" ");
  D(String(myWM->getConfigPortalSSID()));
}


static bool wifiBegin(bool forcePortal) {
	wmShouldSave = false;

	normalizeAppConfigDefaults();

	uint16_t portForUi   = appConfig.MQTTPort;
	uint16_t tempForUi   = appConfig.temperatureUpdateRate;
	uint16_t statusForUi = appConfig.statusUpdateRate;
	
	snprintf(wmMqttPort,   sizeof(wmMqttPort),   "%u", (unsigned)portForUi);
	snprintf(wmTempRate,   sizeof(wmTempRate),   "%u", (unsigned)tempForUi);
	snprintf(wmStatusRate, sizeof(wmStatusRate), "%u", (unsigned)statusForUi);

	// Fresh manager state each time we enter provisioning
	wm.setSaveConfigCallback(wmSaveCallback);
	wm.setBreakAfterConfig(true);
	wm.setConnectTimeout(20);
	wm.setConfigPortalTimeout(180);
	
	if(!wmParamsAdded) {
		wm.addParameter(&pMqttBroker);
		wm.addParameter(&pMqttPort);
		wm.addParameter(&pTempRate);
		wm.addParameter(&pStatusRate);
		wmParamsAdded = true;
	}	

	WiFi.mode(WIFI_STA);

	char apName[32];
	snprintf(apName, sizeof(apName), "%s %s", ACCESSPOINT_NAME, systemID);
	const char* apPass = "12345678";

	static const char wmHead[] PROGMEM = R"rawliteral(
<style>
:root{--bg:#000000;--text:#fff;--card:#20202080;--border:rgba(43,14,161,.75);--shadow:0 12px 30px rgba(0,0,0,.10);--radius:8px;}
html,body{height:100%;}
body{margin:0;color:var(--text);background:var(--bg);font-family:Helvetica,Arial,sans-serif;}
/* card-ish main container */
main, .wrap, .content, form{max-width:560px;margin:4px auto;padding:8px;background:var(--card);border:1px solid var(--border);border-radius:var(--radius);box-shadow:var(--shadow);}
button{padding:12px;}
.wrap{display:block;}
h1,h2,h3{margin:0 0 14px 0;font-size:18px;font-weight:600;background:inherit;}
h3{font-size:12px;font-weight:300;}
input,button,select{font:inherit;}
button,input[type=submit]{border-radius:var(--radius);cursor:pointer;background-color:#c4c4c4;color:#000;font-weight:600}
</style>
	)rawliteral";

	wm.setCustomHeadElement(wmHead);
	wm.setDarkMode(true);
	wm.setTitle("Agent Configuration");
	wm.setAPCallback(configModeCallback);
 	wm.setDebugOutput(false);

	bool ok = false;
	if(forcePortal) {
		Serial.println(F("WiFi: Start Config Portal"));
		ok = wm.startConfigPortal(apName, apPass);
	} else {
		Serial.println(F("WiFi: Auto Connect"));
		D(F("Connecting ..."));
		ok = wm.autoConnect(apName, apPass);
	}

	if (!ok) {
		Serial.println(F("WiFiManager: failed to connect, portal exited."));
		return false;
	}

	D(F("Connected."));

	// Persist YOUR config model if portal saved
	if (wmShouldSave) {
		strlcpy(appConfig.MQTTBroker,
		        pMqttBroker.getValue(),
		        sizeof(appConfig.MQTTBroker));

		appConfig.MQTTPort =
			parseU16(pMqttPort.getValue(), DEFAULT_MQTT_PORT);

		appConfig.temperatureUpdateRate =
			parseU16(pTempRate.getValue(), DEFAULT_TEMP_RATE);

		appConfig.statusUpdateRate =
			parseU16(pStatusRate.getValue(), DEFAULT_STATUS_RATE);

		saveConfiguration(CONFIG_FILE, appConfig);
	}

	return true;
}


static bool wifiReady() {
// Serial.print("wifiReady() ");
// 	wl_status_t st = (wl_status_t)WiFi.status();
// 	Serial.printf("WiFi: Retry. st=%s mode=%d.\n",
// 		wifiStatusStr(st),
// 		(int)WiFi.getMode());

	if(WiFi.status() != WL_CONNECTED) return false;
	IPAddress ip = WiFi.localIP();

	return (ip[0] != 0 || ip[1] != 0 || ip[2] != 0 || ip[3] != 0);
}

static const char* wifiStatusStr(wl_status_t st) {
	switch(st) {
		case WL_IDLE_STATUS:     return "IDLE";
		case WL_NO_SSID_AVAIL:   return "NO_SSID";
		case WL_SCAN_COMPLETED:  return "SCAN_DONE";
		case WL_CONNECTED:       return "CONNECTED";
		case WL_CONNECT_FAILED:  return "CONNECT_FAILED";
		case WL_CONNECTION_LOST: return "CONNECTION_LOST";
		case WL_DISCONNECTED:    return "DISCONNECTED";
		default:                 return "UNKNOWN";
	}
}

static void wifiConnect() {
	WiFi.mode(WIFI_STA);
	WiFi.begin();
}

static void wifiRetryTick() {
	if(wifiReady()) {
		wifiIdleSince = 0;
		return;
	}

	uint32_t now = millis();
	if((int32_t)(now - wifiNextRetry) < 0) return;

// 	Serial.println(F("WiFi: wifiRetryTick()"));
	
	wl_status_t st = (wl_status_t)WiFi.status();
	IPAddress ip = WiFi.localIP();

	Serial.printf("WiFi: Retry. st=%s mode=%d ip=%s.\n",
		wifiStatusStr(st),
		(int)WiFi.getMode(),
		ip.toString().c_str());

	// Track how long we've been stuck in IDLE
	if(st == WL_IDLE_STATUS) {
		if(!wifiIdleSince) wifiIdleSince = now;
	} else if(st == WL_NO_SSID_AVAIL) {
		Serial.println(F("WiFi: No SSID. Giving up."));
		D("Timeout."); 
		rebootTime = 0; // very in the past. Reboot.
	} else {
		wifiIdleSince = 0;
	}

	// Case 1: "CONNECTED but no IP" => bounce DHCP by cycling link
	if (st == WL_CONNECTED && ip == IPAddress(0, 0, 0, 0)) {
		Serial.println(F("WiFi: Connected, No-IP -> disconnect + reconnect."));
		WiFi.disconnect(false);
		delay(200);
		wifiConnect();
		wifiNextRetry = now + 2000UL;
		return;
	}

	// Case 2: If we've been IDLE too long, force a reconnect
	if(wifiIdleSince && (uint32_t)(now - wifiIdleSince) > 15000UL) {
		Serial.println(F("WiFi: IDLE -> reconnecting."));
		wifiIdleSince = 0;

		WiFi.disconnect(false);
		delay(200);

		wifiConnect();

		wifiNextRetry = now + 5000UL;
		return;
	}

	wifiConnect();
	wifiNextRetry = now + WIFI_RETRY_PERIOD;
}

static void handleUploadPage()
{
	if(!wifiEverUp) return;

	// Minimal page: choose .bin and POST it
	static const char uploadHtml[] =
		"<!doctype html><html><head><meta charset='utf-8'>"
		"<meta name='viewport' content='width=device-width,initial-scale=1'>"
		"<title>Update Firmware</title>"
		"<style>"
		":root{--bg:#000000;--text:#fff;--card:#20202080;--border:rgba(43,14,161,0.58);--shadow:0 12px 30px rgba(0,0,0,.10);--radius:8px}"
		"html,body{height:100%;}"
		"body{margin:0;color:var(--text);background:var(--bg);font-family:Helvetica,Arial,sans-serif;}"
		".card{max-width:560px;margin:10vh auto;padding:24px;background:var(--card);border:1px solid var(--border);border-radius:var(--radius);box-shadow:var(--shadow);}"
		".row{display:flex;gap:8px;align-items:center;}"
		".row button{margin-left:auto;}"
		"h3{margin:0 0 14px 0;font-size:18px;font-weight:600;}"
		"input,button{font:inherit;}"
		"button{margin-left:8px;border-radius:var(--radius);background:#fff;cursor:pointer;}"
		"</style>"
		"</head><body>"
		"<div class='card'>"
		"<h3>Update Firmware</h3>"
		"<form method='POST' action='/upload' enctype='multipart/form-data'>"
		"<div class='row'>"
		"<input type='file' name='firmware' accept='.bin' required>"
		"<button type='submit'>Update</button>"
		"</div>"
		"</form>"
		"</div>"
		"</body></html>";

	Server.send(200, "text/html", uploadHtml);
}

static void handleUploadPost()
{
	// Called after upload completes (success or failure)
	if (Update.hasError()) {
		String msg = "Update failed.\n";
		Server.send(500, "text/plain", msg);
		return;
	}

	Server.send(200, "text/plain", "Update OK. Rebooting...\n");
	shouldReboot = true; // reboot in loop after response is sent
}
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
void loop() {
	if (millis() >= rebootTime) {
		reboot();
	}
	// Button Down
	if (rebootPressedTime > 0 && (long)(millis() - rebootPressedTime) >= 0) {
		reboot();
	}
	
	if (wifiProvisioning) {
		if (wifiReady()) {
			wifiProvisioning = false;
			wifiEverUp = true;
		}

		return;
	}
	
	// only here:
	wifiRetryTick();
	
	bool wasUp = wifiEverUp;

	if(!wifiReady()) {
		wifiEverUp = false;

		// Optional: only log on transition
		if(wasUp) {
			D(F("WiFi: Unavailable"));
			Serial.println(F("WiFi: Unavailable"));
		}

		return;
	}

	// WiFi is up
	if(!wasUp) {
		D(F("WiFi: Available"));
		Serial.println(F("WiFi: Available"));
		wifiEverUp = true;
		wifiProvisioning = false;
#if IS_ESP8266
		WiFi.setAutoConnect(true);
		WiFi.setAutoReconnect(true);
#elif IS_ESP32
		WiFi.setAutoReconnect(true);
#endif
 		lastMQTTOnlineCheck = 0; // force immediate MQTT attempt
	}

	bool isConnected = client.loop();
	if((strlen(appConfig.MQTTBroker) > 0) && !isConnected) {
		if(millis() > lastMQTTOnlineCheck) {
			timer.cancel(happyBlinkTimer);
			timer.cancel(temperatureTimer);
			timer.cancel(statusTimer);

			D(F("MQTT: Reconnecting ..."));
			Serial.println("MQTT: Reconnecting ...");
			mqttConnect();
			mqttSubscribe();

			lastMQTTOnlineCheck = millis() + ONLINE_CHECK_PERIOD;
		}
	}

	Server.handleClient();
	delay(0);

	if (shouldReboot) {
		D(F("Rebooting ..."));
		reboot();
	}

#ifdef USE_DFPLAYER
	if (dfp.available()) {
		dfpPrintDetail(dfp.readType(), dfp.read());
	}
#endif

	timer.tick();
	
	bool is_reset = digitalRead(PIN_RESET_WIFI);
	if(!is_reset && !reset_is_down) {
		reset_is_down = true;
		rebootPressedTime = millis() + REBOOT_BUTTON_TIME;
		D("MQTT Agent, V " + String(VERSION));
		D("");
		D("IP: " + WiFi.localIP().toString());
		D("ID: " + String(systemID));
		Serial.println("WiFi: IP: " + WiFi.localIP().toString());
	}
	is_reset = digitalRead(PIN_RESET_WIFI);
	if(is_reset && reset_is_down) {
		reset_is_down = false;
		rebootPressedTime = 0;
	}
	
#ifdef USE_STATUS_0
	bool status0 = ! digitalRead(PIN_STATUS_0);
#else
	bool status0 = false;
#endif
#ifdef USE_STATUS_1
	bool status1 = ! digitalRead(PIN_STATUS_1);
#else
	bool status1 = false;
#endif

	if((status0 != lastStatus0) || (status1 != lastStatus1)) {
		publishStatus((void *)0);
		lastStatus0 = status0;
		lastStatus1 = status1;
	}
}

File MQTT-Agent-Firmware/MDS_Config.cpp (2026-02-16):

#include "MDS_Config.h"
#include <functional>
#include <FS.h>
#if IS_ESP8266 || IS_ESP32
	#include <LittleFS.h>
#endif

#define CONFIG_FILE			"/config.json"
#define CONFIG_DOC_SIZE		512


MDS_Config::MDS_Config() {
}

MDS_Config::~MDS_Config() {
}

void MDS_Config::setup() {
//	Serial.println(F("MDS_Config::setup"));
#if IS_ESP32
	LittleFS.begin(true);   // format-on-fail is handy on ESP32
#else
	LittleFS.begin();
#endif
}

void MDS_Config::load() {
//	Serial.println(F("MDS_Config::load"));
	File file = LittleFS.open(CONFIG_FILE, "r");

	if(file) {
		StaticJsonDocument<CONFIG_DOC_SIZE> doc;

		DeserializationError error = deserializeJson(doc, file);

		if(error) {
			Serial.print(F("Unable to read configuration: "));
			Serial.println(error.c_str());
		} else {
			setDataCallback(doc);
		} 

		file.close();
	} else {
		Serial.print(F("Unable to read configuration '"));
		Serial.print(CONFIG_FILE);
		Serial.println(F("': not found."));
	}
}


void MDS_Config::save() {
//	Serial.println(F("MDS_Config::save()"));

	LittleFS.remove(CONFIG_FILE);

	File file = LittleFS.open(CONFIG_FILE, "w");
	if (!file) {
		Serial.println(F("Unable to create configuration file"));
		return;
	}

	StaticJsonDocument<CONFIG_DOC_SIZE> doc;

	getDataCallback(doc);

	if (serializeJson(doc, file) == 0) {
		Serial.println(F("Unable to write configuration."));
	}

	file.close();
}


void MDS_Config::print() {
//	Serial.println(F("MDS_Config::printFile()"));

	File file = LittleFS.open(CONFIG_FILE, "r");
	if (!file) {
		Serial.println(F("Unable to read file"));
		return;
	}

	while (file.available()) {
		Serial.print((char)file.read());
	}
	Serial.println();

	file.close();
}


void MDS_Config::setSetConfigCallback(std::function<void(StaticJsonDocument<CONFIG_DOC_SIZE>&)> callback) {
//	Serial.println(F("MDS_Config::setSetConfigCallback"));
	setDataCallback = callback;
}


void MDS_Config::setGetConfigCallback(std::function<void(StaticJsonDocument<CONFIG_DOC_SIZE>&)> callback) {
//	Serial.println(F("MDS_Config::setGetConfigCallback"));
	getDataCallback = callback;
}

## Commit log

2020-11-07 Initial add of Arduino Firmware
2020-11-07 Initial add of KiCAD Project
    [MQTT Relay-B_Cu.gbr, MQTT Relay-B_Mask.gbr, MQTT Relay-B_Paste.gbr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]
2023-07-31 Added DFPlayer support
    [MQTT Relay.kicad_pcb, MQTT Relay.kicad_sch]
2023-11-23 Version 3.0 Board
    Integrated relays and SMD
    [MQTT Relay.kicad_pcb, MQTT Relay.kicad_sch]
2024-01-02 Added Relays onBoard
    [MQTT Relay.kicad_pcb, MQTT Relay.kicad_sch]
2024-01-02 Version 1.6
    Fixed (I hope) configuration loss when power fails. Dumb.
    Cleaned up configuration reporting and logic.
2026-02-15 Renamed 8266_MQTTAgent to MQTT-Agent-Firmware as it is no-longer board-specific.
2026-02-15 Renaming MQTT Relay KiCAD Project to MQTT-Agent-Hardware
    [MQTT Relay-B_Cu.gbr, MQTT Relay-B_Mask.gbr, MQTT Relay-B_Paste.gbr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]
2026-02-15 Reorganize Gerbers into a subfolder
    [MQTT Relay-B_Cu.gbr, MQTT Relay-B_Mask.gbr, MQTT Relay-B_Paste.gbr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]
2026-02-15 Transitioning to ESP32 and modular PCB approach
    [ESP32c6 Agent PCB CPU-B_Cu.gbr, ESP32c6 Agent PCB CPU-B_Mask.gbr, ESP32c6 Agent PCB CPU-B_Paste.gbr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]
2026-02-16 Added ESP32c6 Support
2026-02-21 More cleanup
    Cleaned up WiFi Connection failures.
    Fixed AP name
    [MQTT-Agent-Firmware.ino]
2026-02-21 Added multi-sensor support for 1-wire temperature
2026-02-26 Added average temperature
2026-02-26 Added 10-second button → reboot
    [MQTT-Agent-Firmware.ino]
2026-03-08 Cleanup and Finalize.
    Updated footprints.
    cleaned up silkscreen.
    Changed schematic to B-size
    [ESP32c6 Agent PCB CPU.kicad_pcb, ESP32c6 Agent PCB CPU.kicad_sch]
2026-03-09 Generated Gerbers
    [ESP32c6 Agent PCB CPU-B_Cu.gbr, ESP32c6 Agent PCB CPU-B_Mask.gbr, ESP32c6 Agent PCB CPU-B_Paste.gbr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]
2026-03-09 Initial Create
    [ESP32c6 Agent PCB Input.kicad_pcb, ESP32c6 Agent PCB Input.kicad_sch]
2026-03-23 Added configurable relay pulse timing with relayPulseDuration
2026-03-23 Added MQTT example for relay pulse duration
2026-11-09 Switched policy to RetrySavedNetwork

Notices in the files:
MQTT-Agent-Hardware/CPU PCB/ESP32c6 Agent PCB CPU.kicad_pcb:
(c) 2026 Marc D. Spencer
